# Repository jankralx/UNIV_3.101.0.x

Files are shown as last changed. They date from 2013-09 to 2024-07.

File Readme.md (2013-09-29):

UNIV 3.101.0.x
============

RS232C INTERFACE - PC interface and interface to other devices with serial port

Device webpage: http://hapcan.com/devices/universal/univ_3/univ_3-101-0-x/

Hardware created in Eagle PCB Software http://www.cadsoftusa.com/

Firmware created in Microchip MPLAB http://www.microchip.com/mplabide/ in assembly language

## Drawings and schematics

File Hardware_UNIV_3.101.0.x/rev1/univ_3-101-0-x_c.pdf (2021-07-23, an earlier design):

## RS232C INTERFACE

# UNIV 3.101.0.x

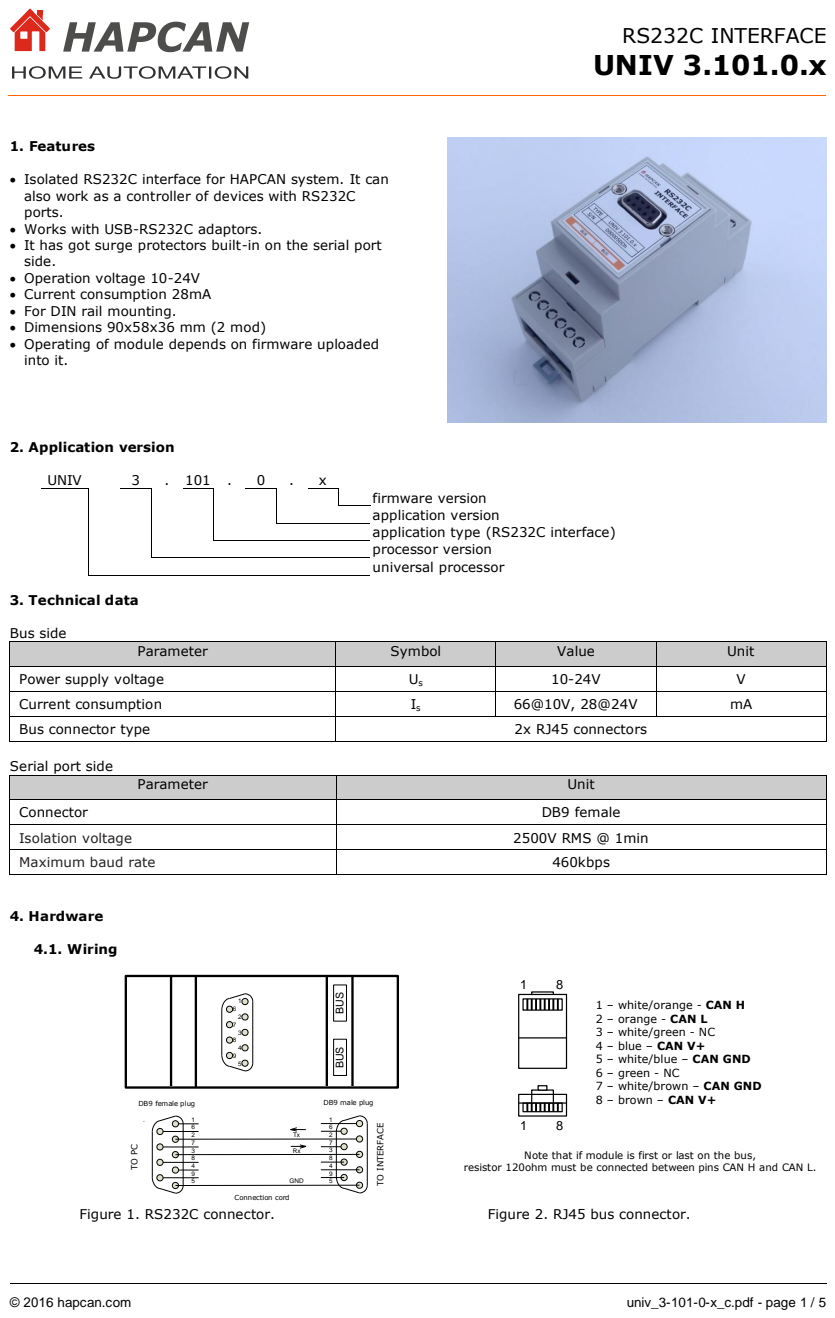
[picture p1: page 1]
© 2016 hapcan.com; univ_3-101-0-x_c.pdf - page 1 / 5; 1. Features; 2. Application version; UNIV; 3. Technical data; Bus side; 4. Hardware; 4.1. Wiring; Figure 1. RS232C connector.; Figure 2. RJ45 bus connector.; DO KOMPUTERA; BUS BUS; DB9 Wtyk żeński; DB9 Wtyk męski; GND; DO INTERFEJSU; PRZEWÓD POŁĄCZENIOWY; TO INTERFACE; Connection cord

• Isolated RS232C interface for HAPCAN system. It can
also work as a controller of devices with RS232C
ports.
• Works with USB-RS232C adaptors.
• It has got surge protectors built-in on the serial port
side.
• Operation voltage 10-24V
• Current consumption 28mA
• For DIN rail mounting.
• Dimensions 90x58x36 mm (2 mod)
• Operating of module depends on firmware uploaded
into it.

firmware version
application version
application type (RS232C interface)
processor version
universal processor

Parameter | Symbol | Value | Unit

Power supply voltage | Us | 10-24V | V

Current consumption | Is | 66@10V, 28@24V | mA

Bus connector type | 2x RJ45 connectors

Serial port side

Parameter | Unit

Connector | DB9 female

Isolation voltage | 2500V RMS @ 1min

Maximum baud rate | 460kbps

1 – white/orange - CAN H
2 – orange - CAN L
3 – white/green - NC
4 – blue – CAN V+
5 – white/blue – CAN GND
6 – green - NC
7 – white/brown – CAN GND
8 – brown – CAN V+

TO PC DB9 female plug DB9 male plug

Note that if module is first or last on the bus,

resistor 120ohm must be connected between pins CAN H and CAN L.

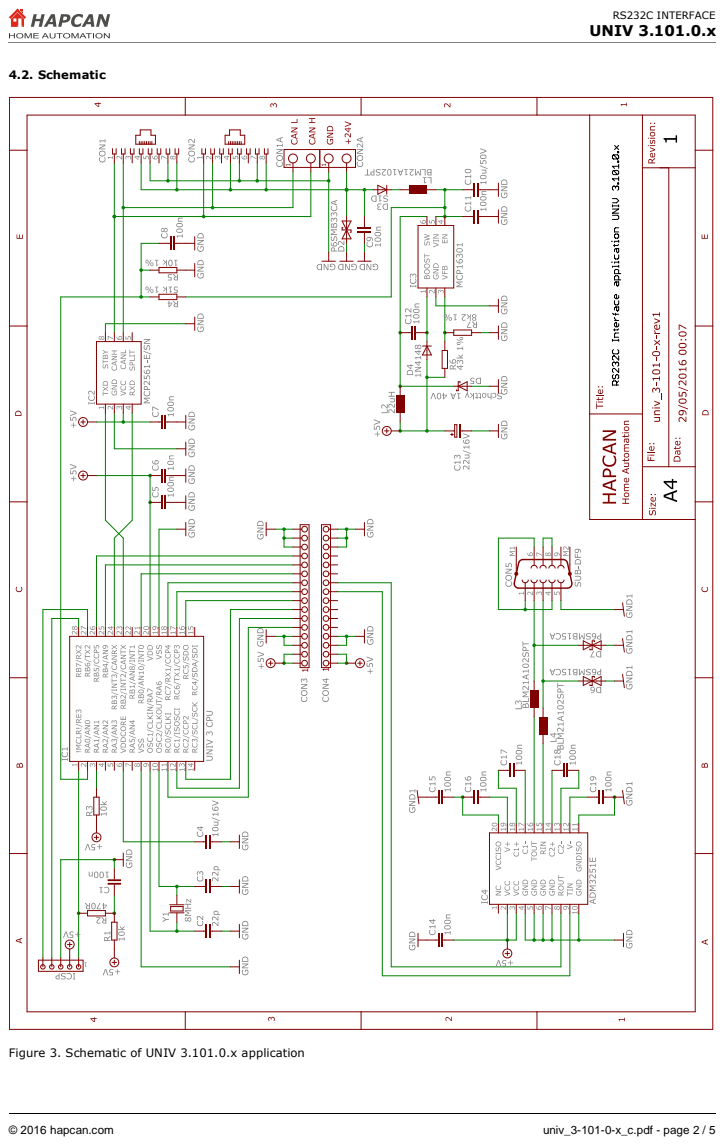
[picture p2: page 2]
4.2. Schematic

Figure 3. Schematic of UNIV 3.101.0.x application

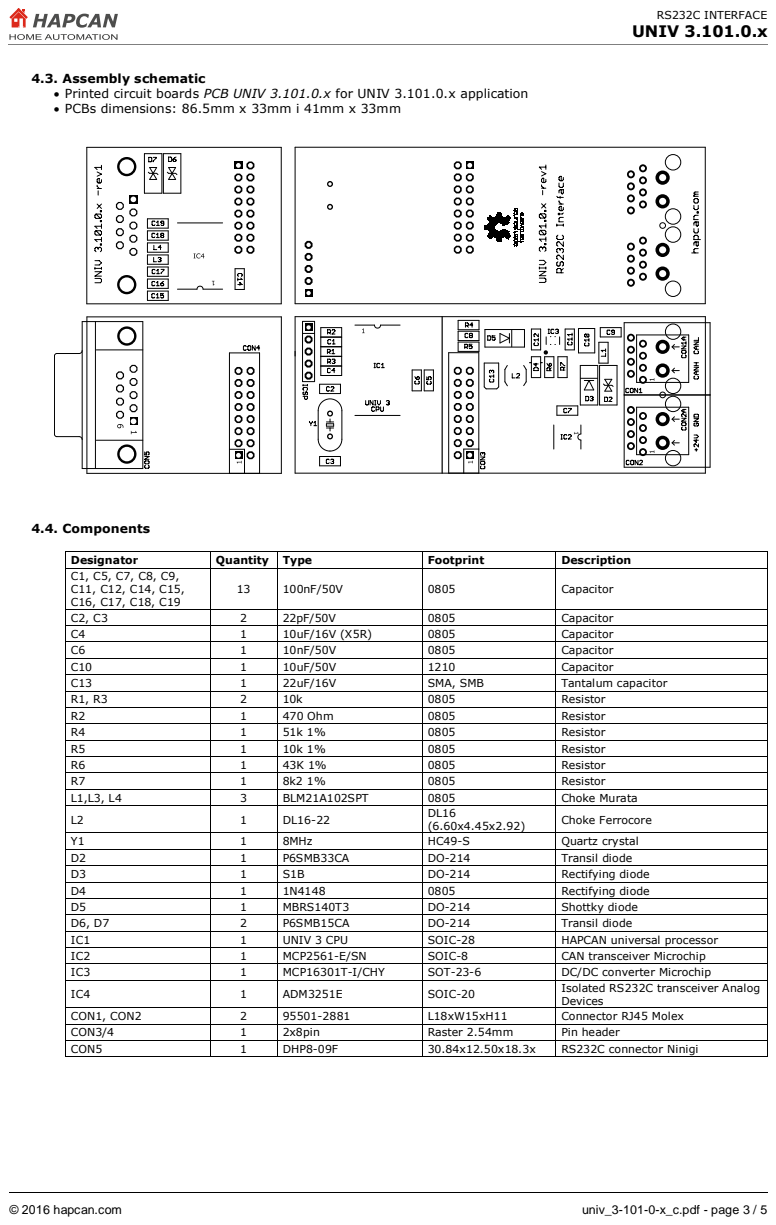
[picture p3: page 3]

4.3. Assembly schematic
• Printed circuit boards PCB UNIV 3.101.0.x for UNIV 3.101.0.x application
• PCBs dimensions: 86.5mm x 33mm i 41mm x 33mm

Designator | Quantity | Type | Footprint | Description
C1, C5, C7, C8, C9, C11, C12, C14, C15, C16, C17, C18, C19 | 13 | 100nF/50V | 0805 | Capacitor

C2, C3 | 2 | 22pF/50V | 0805 | Capacitor
C4 | 1 | 10uF/16V (X5R) | 0805 | Capacitor
C6 | 1 | 10nF/50V | 0805 | Capacitor
C10 | 1 | 10uF/50V | 1210 | Capacitor
C13 | 1 | 22uF/16V | SMA, SMB | Tantalum capacitor
R1, R3 | 2 | 10k | 0805 | Resistor
R2 | 1 | 470 Ohm | 0805 | Resistor
R4 | 1 | 51k 1% | 0805 | Resistor
R5 | 1 | 10k 1% | 0805 | Resistor
R6 | 1 | 43K 1% | 0805 | Resistor
R7 | 1 | 8k2 1% | 0805 | Resistor
L1,L3, L4 | 3 | BLM21A102SPT | 0805 | Choke Murata
L2 | 1 | DL16-22 | DL16 (6.60x4.45x2.92) | Choke Ferrocore

Y1 | 1 | 8MHz | HC49-S | Quartz crystal
D2 | 1 | P6SMB33CA | DO-214 | Transil diode
D3 | 1 | S1B | DO-214 | Rectifying diode
D4 | 1 | 1N4148 | 0805 | Rectifying diode
D5 | 1 | MBRS140T3 | DO-214 | Shottky diode
D6, D7 | 2 | P6SMB15CA | DO-214 | Transil diode
IC1 | 1 | UNIV 3 CPU | SOIC-28 | HAPCAN universal processor
IC2 | 1 | MCP2561-E/SN | SOIC-8 | CAN transceiver Microchip
IC3 | 1 | MCP16301T-I/CHY | SOT-23-6 | DC/DC converter Microchip
IC4 | 1 | ADM3251E | SOIC-20 | Isolated RS232C transceiver Analog Devices

CON1, CON2 | 2 | 95501-2881 | L18xW15xH11 | Connector RJ45 Molex
CON3/4 | 1 | 2x8pin | Raster 2.54mm | Pin header
CON5 | 1 | DHP8-09F | 30.84x12.50x18.3x | RS232C connector Ninigi

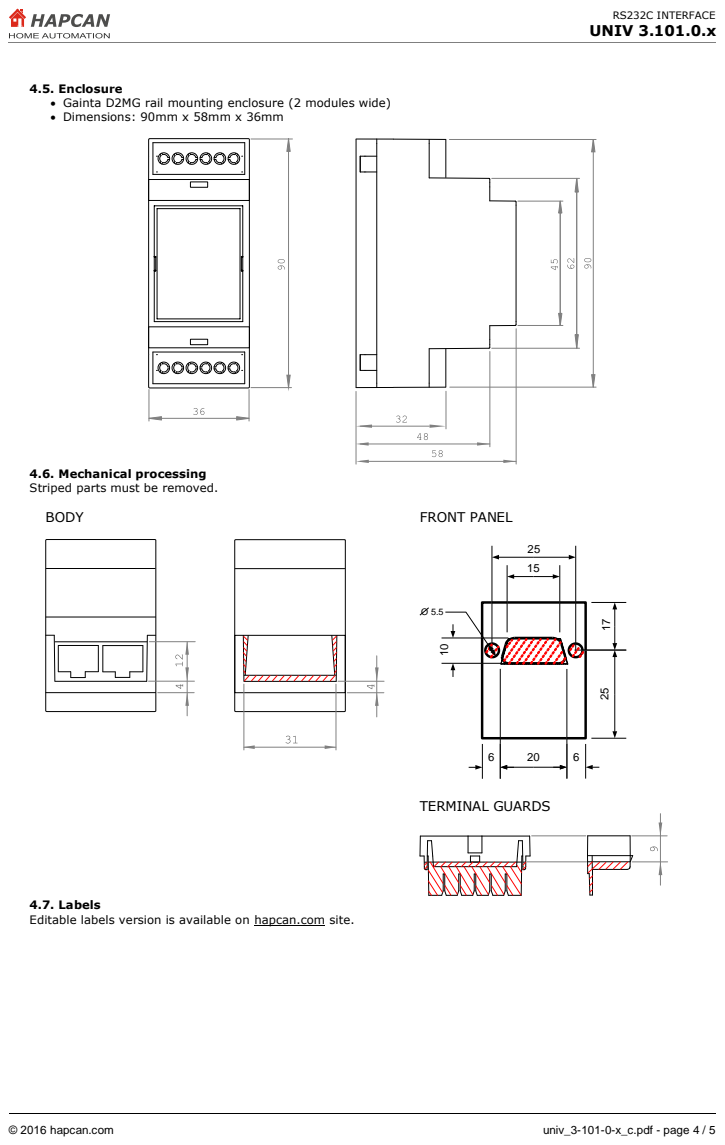
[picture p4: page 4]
BODY; FRONT PANEL; TERMINAL GUARDS

4.5. Enclosure
• Gainta D2MG rail mounting enclosure (2 modules wide)
• Dimensions: 90mm x 58mm x 36mm

4.6. Mechanical processing
Striped parts must be removed.

4.7. Labels
Editable labels version is available on hapcan.com site.

RS232C
Interface
TYPE | UNIV 3.101.0.x
S/N | 0000050Dh
BUS | BUS

### 5. Commissioning

### 5.1. CPU voltage measurement

After verifying the correctness and quality of the soldering, the bus voltage should be connected while measuring the processor voltage. To do this, connect a voltmeter to pins 2 and 3 of the ICSP connector. Processor supply voltage should be about 5V.

Figure 4. CPU voltage measurement

### 5.2. Checking the CPU clock

Proper operation of the CPU can be checked by temporarily connecting the LED to pins 3 and 5 of the ICSP connector. When device is powered, the LED should light up four times in the sequence 0.5 second on - 0.5 second off. If the processor is in programming mode, the LED lights up only once for 50ms.

Figure 5. Checking the CPU clock

### 5.3. Firmware uploading

The device requires a firmware uploading for proper operation. It can be done with HAPCAN Programmer software. Both, firmware and HAPCAN Programmer can be downloaded from hapcan.com website.
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

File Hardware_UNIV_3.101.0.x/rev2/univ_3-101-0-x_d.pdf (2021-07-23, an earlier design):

## RS232C INTERFACE

# UNIV 3.101.0.x

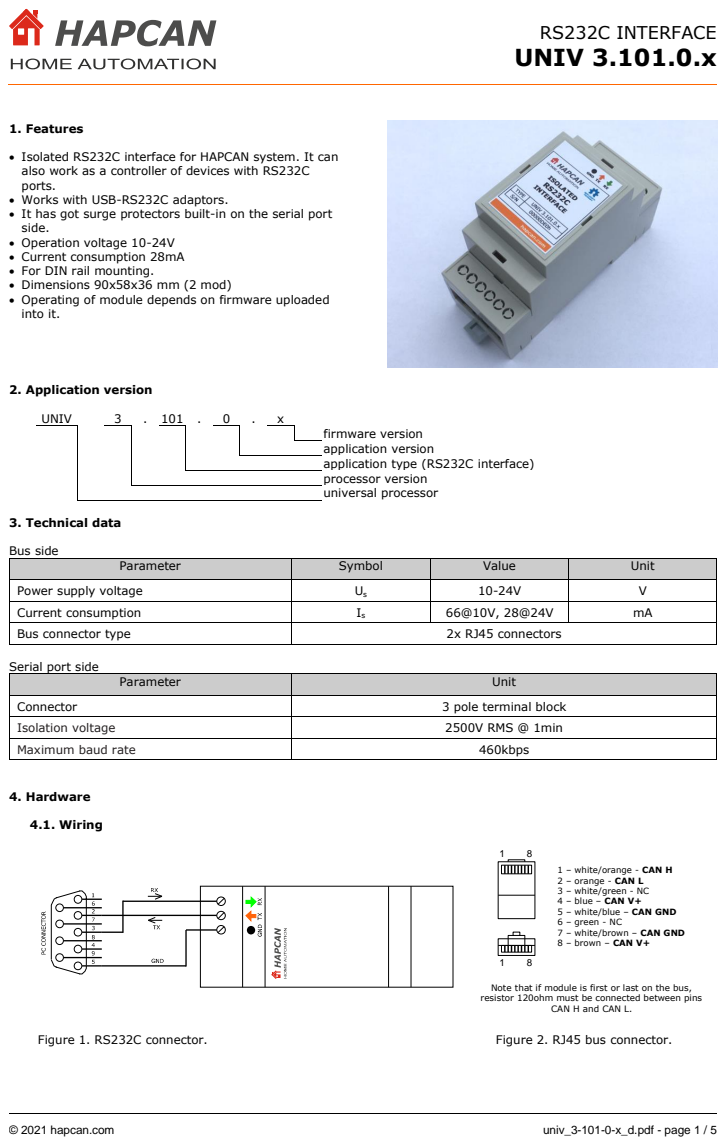
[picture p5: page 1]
© 2021 hapcan.com; univ_3-101-0-x_d.pdf - page 1 / 5; 1. Features; 2. Application version; UNIV; 3. Technical data; Bus side; 4. Hardware; 4.1. Wiring; Figure 1. RS232C connector.; Figure 2. RJ45 bus connector.

• Isolated RS232C interface for HAPCAN system. It can
also work as a controller of devices with RS232C
ports.
• Works with USB-RS232C adaptors.
• It has got surge protectors built-in on the serial port
side.
• Operation voltage 10-24V
• Current consumption 28mA
• For DIN rail mounting.
• Dimensions 90x58x36 mm (2 mod)
• Operating of module depends on firmware uploaded
into it.

firmware version
application version
application type (RS232C interface)
processor version
universal processor

Parameter | Symbol | Value | Unit

Power supply voltage | Us | 10-24V | V
Current consumption | Is | 66@10V, 28@24V | mA
Bus connector type | 2x RJ45 connectors

Serial port side

Parameter | Unit

Connector | 3 pole terminal block
Isolation voltage | 2500V RMS @ 1min
Maximum baud rate | 460kbps

1 – white/orange - CAN H
2 – orange - CAN L
3 – white/green - NC
4 – blue – CAN V+
5 – white/blue – CAN GND
6 – green - NC
7 – white/brown – CAN GND
8 – brown – CAN V+

Note that if module is first or last on the bus,
resistor 120ohm must be connected between pins

CAN H and CAN L.

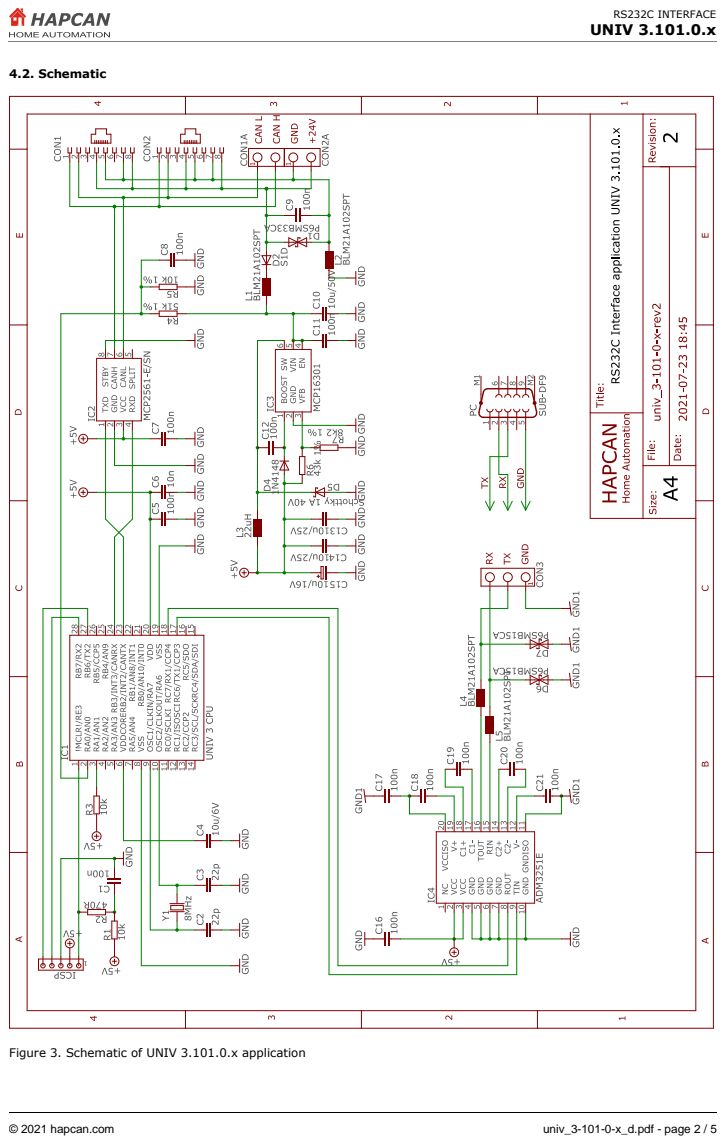
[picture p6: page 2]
4.2. Schematic

Figure 3. Schematic of UNIV 3.101.0.x application

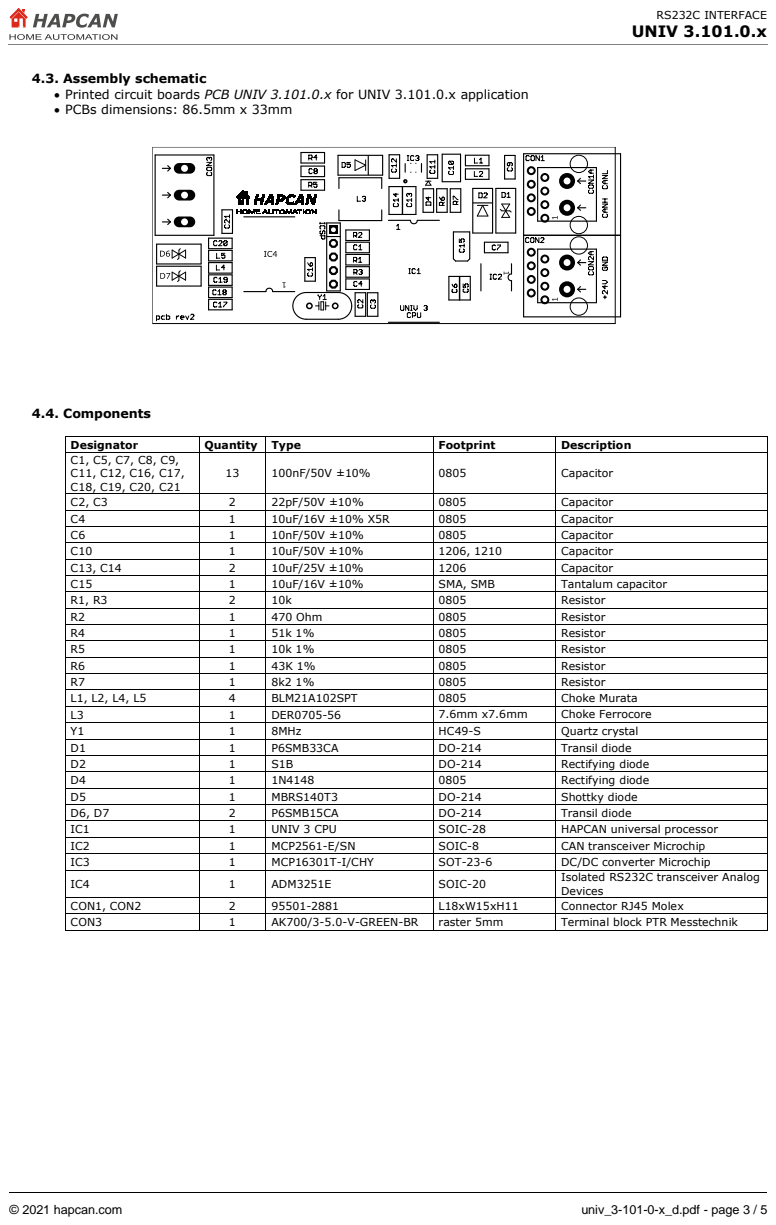
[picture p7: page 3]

4.3. Assembly schematic
• Printed circuit boards PCB UNIV 3.101.0.x for UNIV 3.101.0.x application
• PCBs dimensions: 86.5mm x 33mm

Designator | Quantity | Type | Footprint | Description
C1, C5, C7, C8, C9, C11, C12, C16, C17, C18, C19, C20, C21 | 13 | 100nF/50V ±10% | 0805 | Capacitor

C2, C3 | 2 | 22pF/50V ±10% | 0805 | Capacitor
C4 | 1 | 10uF/16V ±10% X5R | 0805 | Capacitor
C6 | 1 | 10nF/50V ±10% | 0805 | Capacitor
C10 | 1 | 10uF/50V ±10% | 1206, 1210 | Capacitor
C13, C14 | 2 | 10uF/25V ±10% | 1206 | Capacitor
C15 | 1 | 10uF/16V ±10% | SMA, SMB | Tantalum capacitor
R1, R3 | 2 | 10k | 0805 | Resistor
R2 | 1 | 470 Ohm | 0805 | Resistor
R4 | 1 | 51k 1% | 0805 | Resistor
R5 | 1 | 10k 1% | 0805 | Resistor
R6 | 1 | 43K 1% | 0805 | Resistor
R7 | 1 | 8k2 1% | 0805 | Resistor
L1, L2, L4, L5 | 4 | BLM21A102SPT | 0805 | Choke Murata
L3 | 1 | DER0705-56 | 7.6mm x7.6mm | Choke Ferrocore
Y1 | 1 | 8MHz | HC49-S | Quartz crystal
D1 | 1 | P6SMB33CA | DO-214 | Transil diode
D2 | 1 | S1B | DO-214 | Rectifying diode
D4 | 1 | 1N4148 | 0805 | Rectifying diode
D5 | 1 | MBRS140T3 | DO-214 | Shottky diode
D6, D7 | 2 | P6SMB15CA | DO-214 | Transil diode
IC1 | 1 | UNIV 3 CPU | SOIC-28 | HAPCAN universal processor
IC2 | 1 | MCP2561-E/SN | SOIC-8 | CAN transceiver Microchip
IC3 | 1 | MCP16301T-I/CHY | SOT-23-6 | DC/DC converter Microchip
IC4 | 1 | ADM3251E | SOIC-20 | Isolated RS232C transceiver Analog Devices

CON1, CON2 | 2 | 95501-2881 | L18xW15xH11 | Connector RJ45 Molex
CON3 | 1 | AK700/3-5.0-V-GREEN-BR | raster 5mm | Terminal block PTR Messtechnik

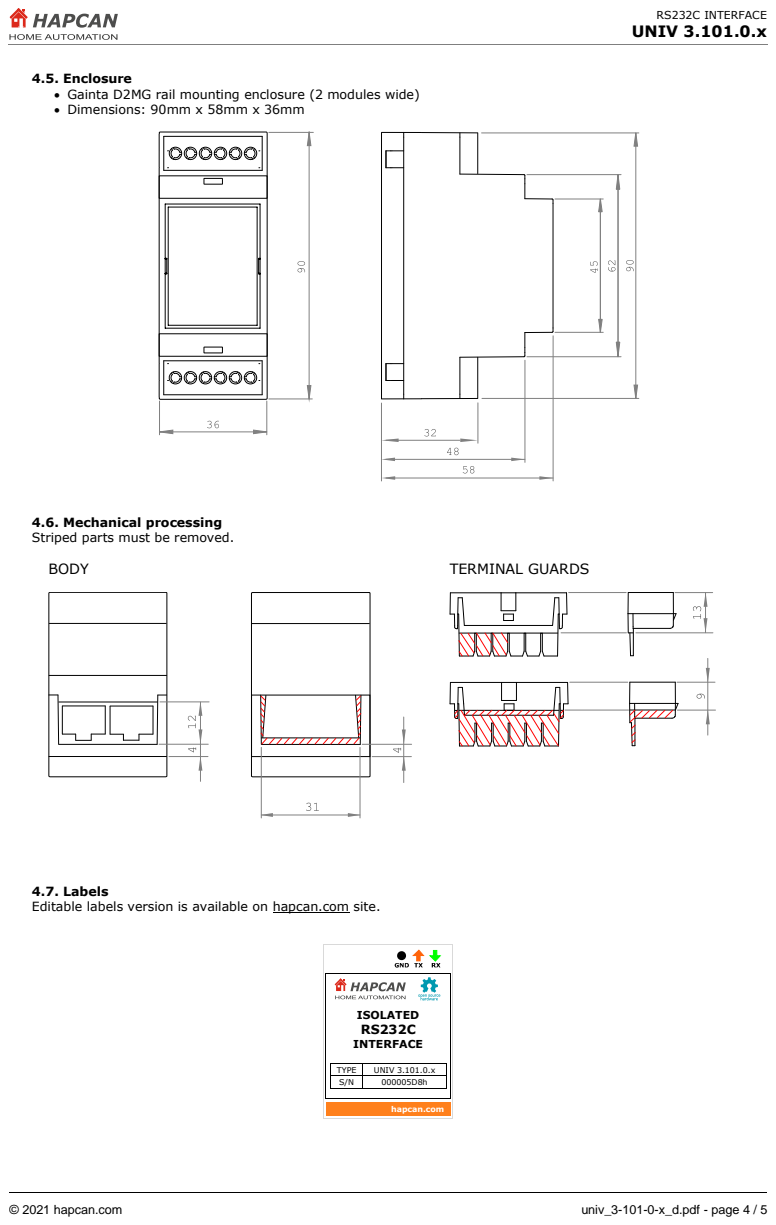
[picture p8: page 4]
BODY; TERMINAL GUARDS; ISOLATED RS232C INTERFACE; hapcan.com

4.5. Enclosure
• Gainta D2MG rail mounting enclosure (2 modules wide)
• Dimensions: 90mm x 58mm x 36mm

4.6. Mechanical processing
Striped parts must be removed.

4.7. Labels
Editable labels version is available on hapcan.com site.

TYPE | UNIV 3.101.0.x
S/N | 000005D8h

### 5. Commissioning

### 5.1. CPU voltage measurement

After verifying the correctness and quality of the soldering, the bus voltage should be connected while measuring the processor voltage. To do this, connect a voltmeter to pins 2 and 3 of the ICSP connector. Processor supply voltage should be about 5V.

Figure 4. CPU voltage measurement

### 5.2. Checking the CPU clock

Proper operation of the CPU can be checked by temporarily connecting the LED to pins 3 and 5 of the ICSP connector. When device is powered, the LED should light up four times in the sequence 0.5 second on - 0.5 second off. The LED lights up only once for 50ms if processor is in the programming mode.

Figure 5. Checking the CPU clock

### 5.3. Firmware uploading

The device requires a firmware uploading for proper operation. It can be done with HAPCAN Programmer software. Both, firmware and HAPCAN Programmer can be downloaded from hapcan.com website.
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

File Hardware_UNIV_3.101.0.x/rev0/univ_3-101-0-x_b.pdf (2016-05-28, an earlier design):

## RS232C INTERFACE

# UNIV 3.101.0.x

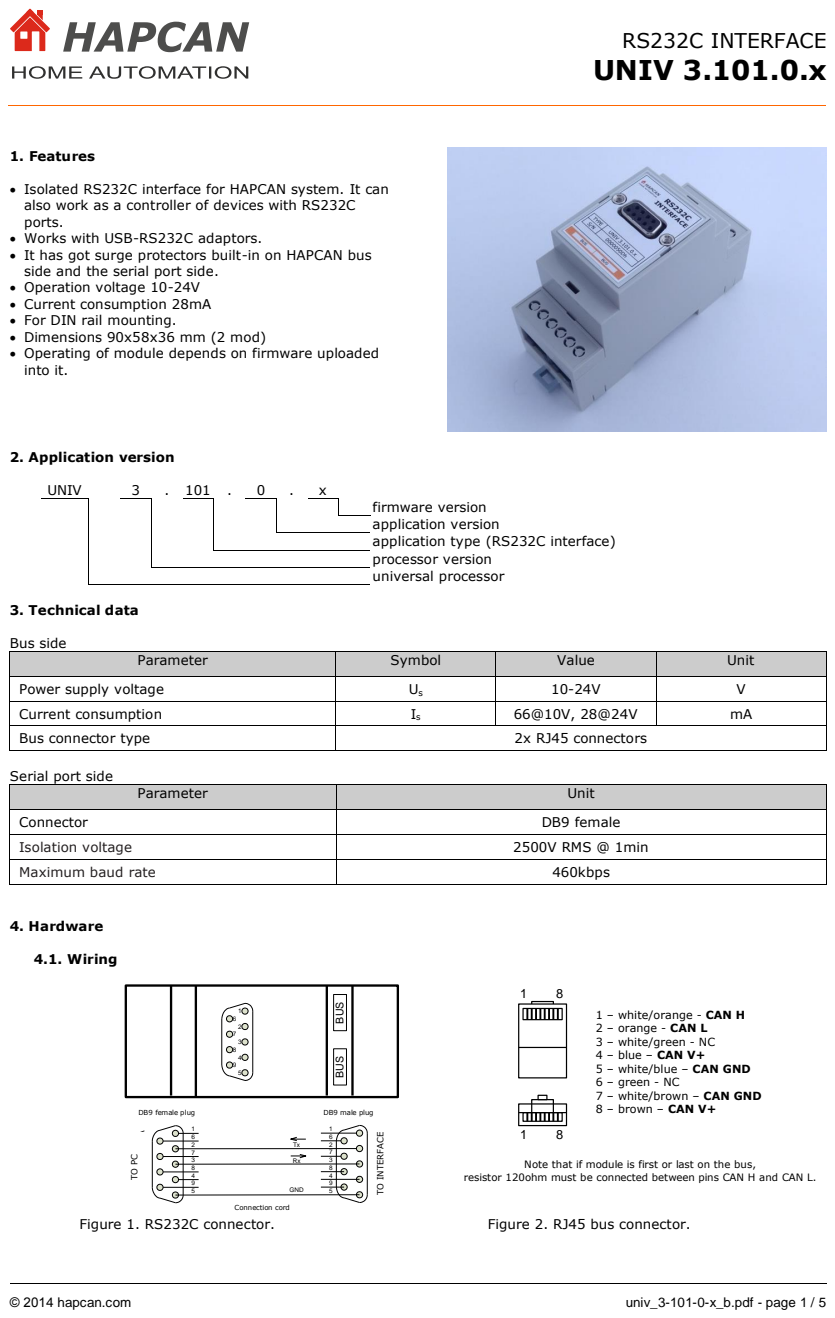
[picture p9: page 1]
© 2014 hapcan.com; univ_3-101-0-x_b.pdf - page 1 / 5; 1. Features; 2. Application version; UNIV; 3. Technical data; Bus side; 4. Hardware; 4.1. Wiring; Figure 1. RS232C connector.; Figure 2. RJ45 bus connector.; DO KOMPUTERA; BUS BUS; DB9 Wtyk żeński; DB9 Wtyk męski; GND; DO INTERFEJSU; PRZEWÓD POŁĄCZENIOWY; TO INTERFACE; Connection cord

• Isolated RS232C interface for HAPCAN system. It can
also work as a controller of devices with RS232C
ports.
• Works with USB-RS232C adaptors.
• It has got surge protectors built-in on HAPCAN bus
side and the serial port side.
• Operation voltage 10-24V
• Current consumption 28mA
• For DIN rail mounting.
• Dimensions 90x58x36 mm (2 mod)
• Operating of module depends on firmware uploaded
into it.

firmware version
application version
application type (RS232C interface)
processor version
universal processor

Parameter | Symbol | Value | Unit

Power supply voltage | Us | 10-24V | V

Current consumption | Is | 66@10V, 28@24V | mA

Bus connector type | 2x RJ45 connectors

Serial port side

Parameter | Unit

Connector | DB9 female

Isolation voltage | 2500V RMS @ 1min

Maximum baud rate | 460kbps

1 – white/orange - CAN H
2 – orange - CAN L
3 – white/green - NC
4 – blue – CAN V+
5 – white/blue – CAN GND
6 – green - NC
7 – white/brown – CAN GND
8 – brown – CAN V+

TO PC DB9 female plug DB9 male plug

Note that if module is first or last on the bus,

resistor 120ohm must be connected between pins CAN H and CAN L.

## UNIV 3.101.0.x

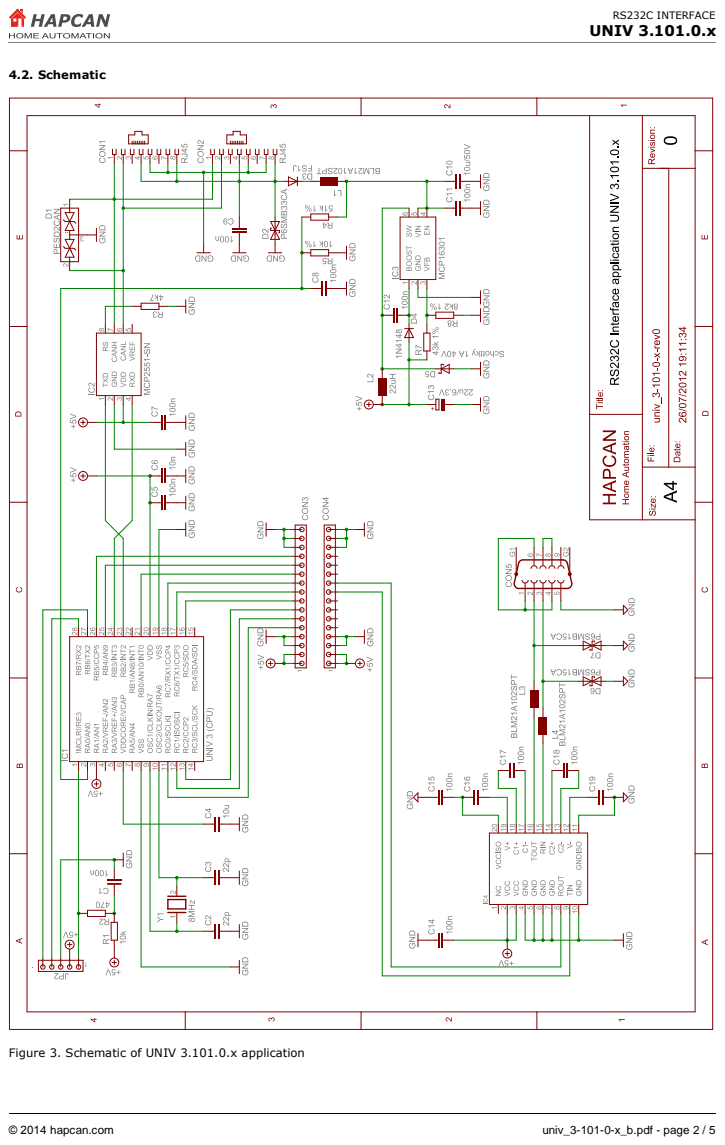
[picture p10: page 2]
4.2. Schematic

Figure 3. Schematic of UNIV 3.101.0.x application

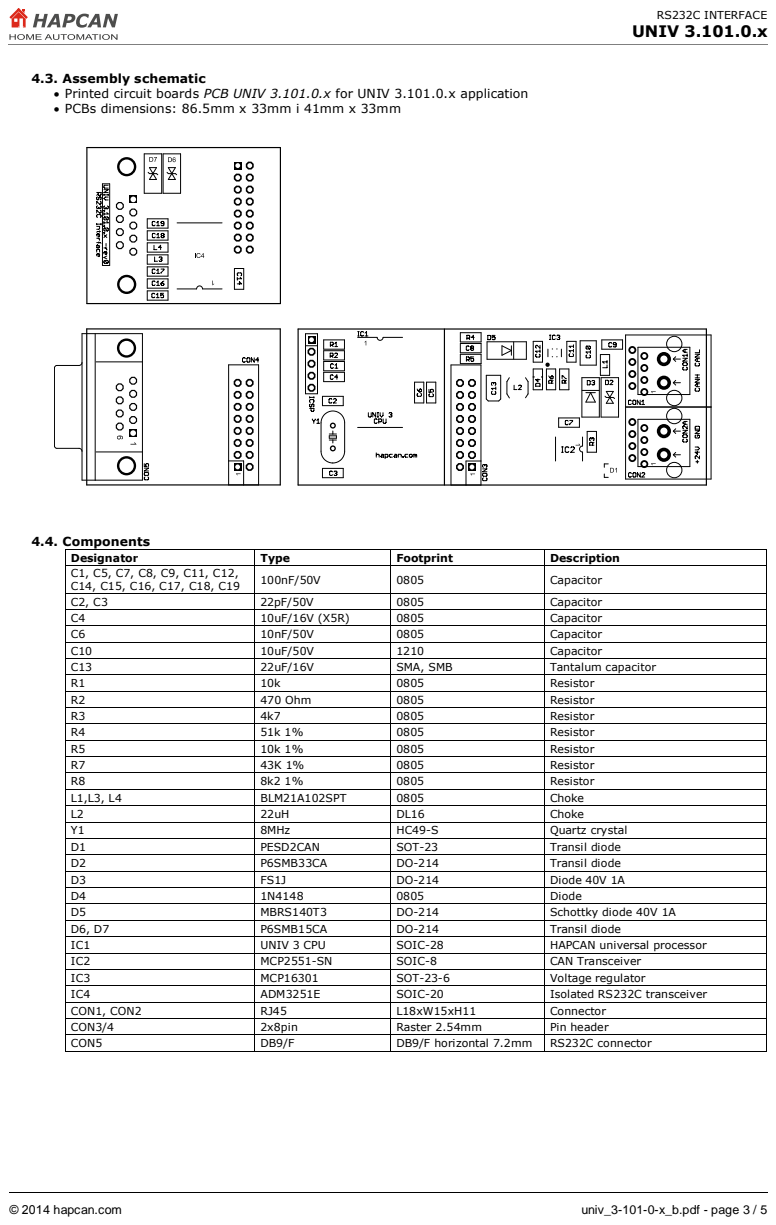
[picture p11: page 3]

4.3. Assembly schematic
• Printed circuit boards PCB UNIV 3.101.0.x for UNIV 3.101.0.x application
• PCBs dimensions: 86.5mm x 33mm i 41mm x 33mm

Designator | Type | Footprint | Description
C1, C5, C7, C8, C9, C11, C12, C14, C15, C16, C17, C18, C19 | 100nF/50V | 0805 | Capacitor

C2, C3 | 22pF/50V | 0805 | Capacitor
C4 | 10uF/16V (X5R) | 0805 | Capacitor
C6 | 10nF/50V | 0805 | Capacitor
C10 | 10uF/50V | 1210 | Capacitor
C13 | 22uF/16V | SMA, SMB | Tantalum capacitor
R1 | 10k | 0805 | Resistor
R2 | 470 Ohm | 0805 | Resistor
R3 | 4k7 | 0805 | Resistor
R4 | 51k 1% | 0805 | Resistor
R5 | 10k 1% | 0805 | Resistor
R7 | 43K 1% | 0805 | Resistor
R8 | 8k2 1% | 0805 | Resistor
L1,L3, L4 | BLM21A102SPT | 0805 | Choke
L2 | 22uH | DL16 | Choke
Y1 | 8MHz | HC49-S | Quartz crystal
D1 | PESD2CAN | SOT-23 | Transil diode
D2 | P6SMB33CA | DO-214 | Transil diode
D3 | FS1J | DO-214 | Diode 40V 1A
D4 | 1N4148 | 0805 | Diode
D5 | MBRS140T3 | DO-214 | Schottky diode 40V 1A
D6, D7 | P6SMB15CA | DO-214 | Transil diode
IC1 | UNIV 3 CPU | SOIC-28 | HAPCAN universal processor
IC2 | MCP2551-SN | SOIC-8 | CAN Transceiver
IC3 | MCP16301 | SOT-23-6 | Voltage regulator
IC4 | ADM3251E | SOIC-20 | Isolated RS232C transceiver
CON1, CON2 | RJ45 | L18xW15xH11 | Connector
CON3/4 | 2x8pin | Raster 2.54mm | Pin header
CON5 | DB9/F | DB9/F horizontal 7.2mm | RS232C connector

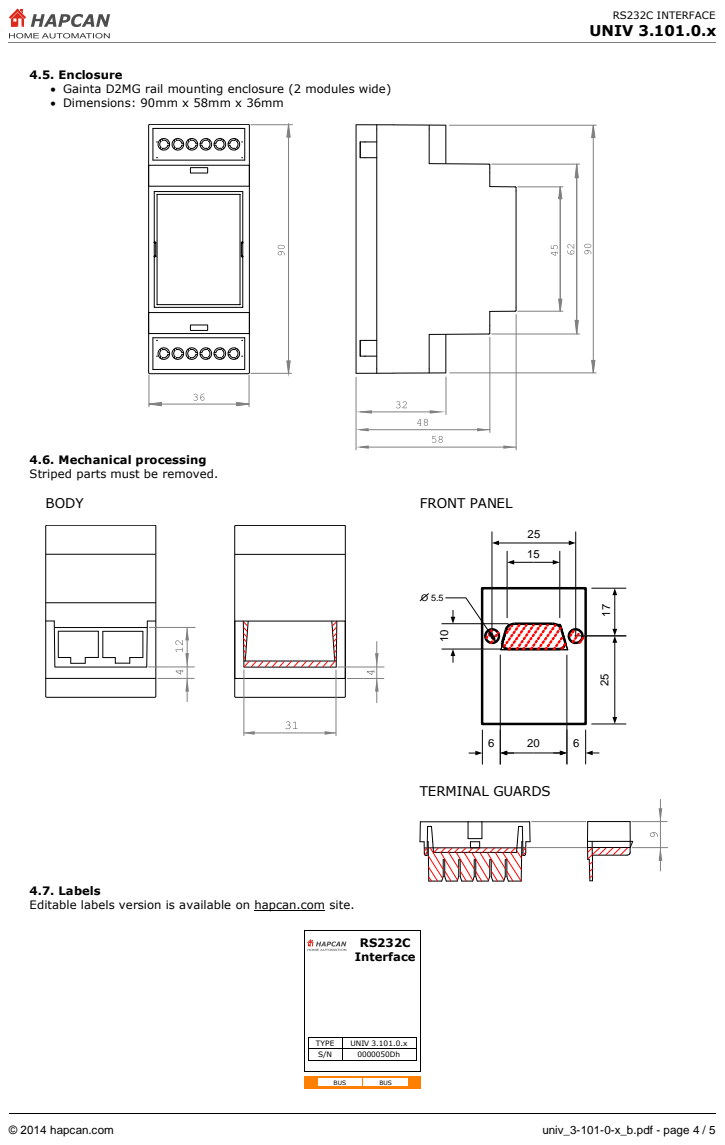
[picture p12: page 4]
BODY; FRONT PANEL; TERMINAL GUARDS; RS232C Interface; BUS

4.5. Enclosure
• Gainta D2MG rail mounting enclosure (2 modules wide)
• Dimensions: 90mm x 58mm x 36mm

4.6. Mechanical processing
Striped parts must be removed.

4.7. Labels
Editable labels version is available on hapcan.com site.

TYPE | UNIV 3.101.0.x
S/N | 0000050Dh

### 5. Commissioning

### 5.1. CPU voltage measurement

After verifying the correctness and quality of the soldering, the bus voltage should be connected while measuring the processor voltage. To do this, connect a voltmeter to pins 2 and 3 of the ICSP connector. Processor supply voltage should be about 5V.

Figure 4. CPU voltage measurement

### 5.2. Checking the CPU clock

Proper operation of the CPU can be checked by temporarily connecting the LED to pins 3 and 5 of the ICSP connector. When device is powered, the LED should light up four times in the sequence 0.5 second on - 0.5 second off. If the processor is in programming mode, the LED lights up only once for 50ms.

Figure 5. Checking the CPU clock

### 5.3. Firmware uploading

The device requires a firmware uploading for proper operation. It can be done with HAPCAN Programmer software. Both, firmware and HAPCAN Programmer can be downloaded from hapcan.com website.

### 6. Document version

File | Description | Date
univ_3-101-0-x_a.pdf | Original version | July 2012
univ_3-101-0-x_b.pdf | Enclosure has been changed | June 2014

1
V

### ICSP

1
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

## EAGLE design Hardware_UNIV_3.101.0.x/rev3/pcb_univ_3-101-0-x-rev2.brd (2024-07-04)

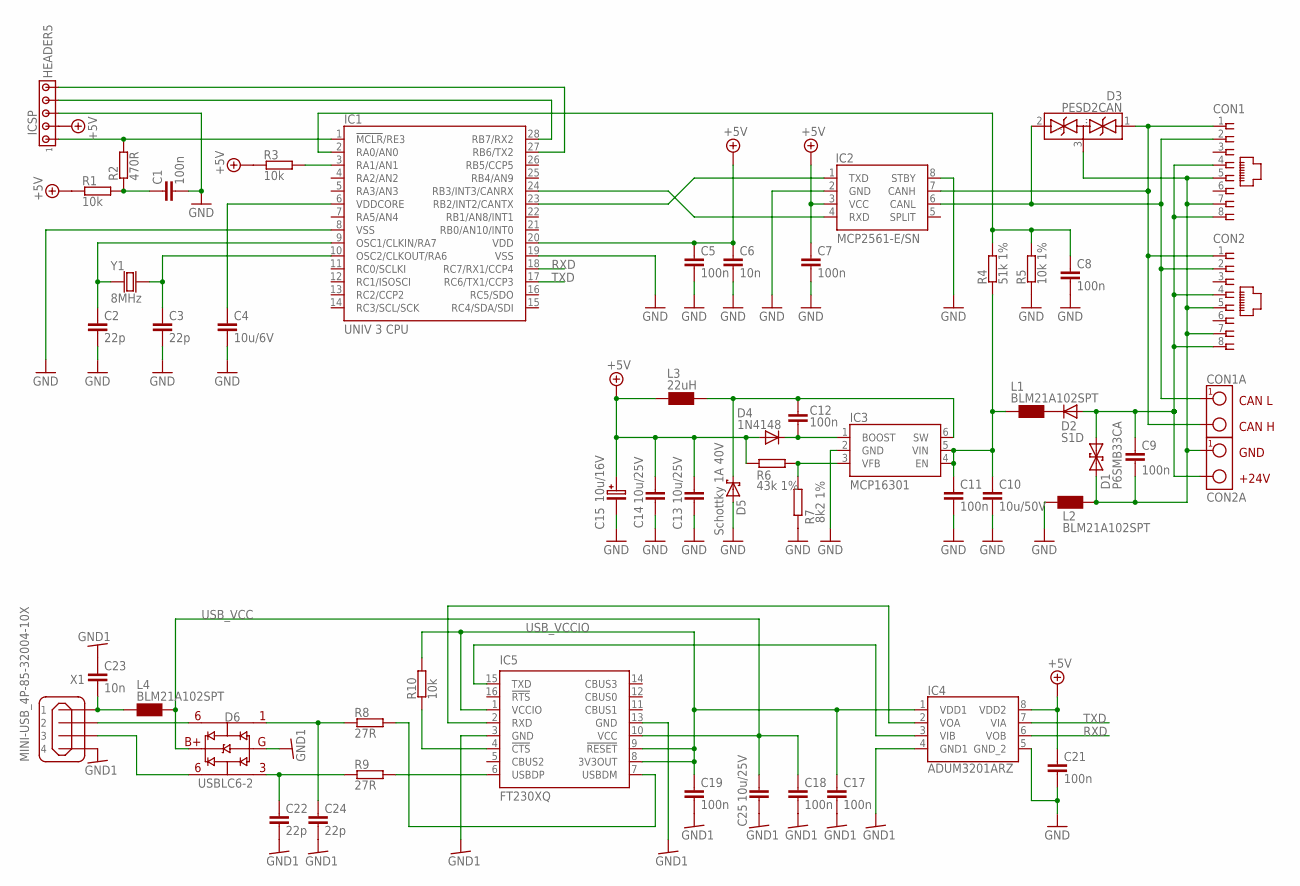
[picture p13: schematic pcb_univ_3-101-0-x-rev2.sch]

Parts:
C1, C5, C7, C8, C9, C11, C12, C17, C18, C19, C21: 100n; 0805
C2, C3, C22, C24: 22p; 0805
C4: 10u/6V; 0805
C6, C23: 10n; 0805
C10: 10u/50V; 1210
C13, C14, C25: 10u/25V; 1206
C15: 10u/16V; SMC_B
CON1, CON2: RJ45-SOCKET; RJ45-PCB-SOCKET
CON1A, CON2A: TERMINAL-2; ARK2-5X10,5MM
D1: P6SMB33CA; DO-214_TRANSIL2
D2: S1D; DO-214
D3: PESD2CAN; SOT-23
D4: 1N4148; 0805
D5: Schottky 1A 40V; DO-214
D6: USBLC6-2; SOT23-6L; MFR_PART_NO USBLC6-2SC6
IC1: UNIV 3 CPU; UNIV3CPU
IC2: MCP2561-E/SN; SO-08
IC3: MCP16301; SOT-23-6
IC4: ADUM3201ARZ; SOIC127P600X175-8N
IC5: FT230XQ; QFN16
ICSP: HEADER5; SIP-5
L1, L2, L4: BLM21A102SPT; 0805
L3: 22uH; CHOKE-DER0705
R1, R3, R10: 10k; 0805
R2: 470R; 0805
R4: 51k 1%; 0805
R5: 10k 1%; 0805
R6: 43k 1%; 0805
R7: 8k2 1%; 0805
R8, R9: 27R; 0805
X1: MINI-USB_4P-85-32004-10X; 85-32004-10X
Y1: 8MHz; CRYSTAL-HC49V

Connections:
+5V: C5.1, C6.1, C7.1, C13.1, C14.1, C15.+ (1), C21.1, D4.2 (A), IC1.20 (VDD), IC2.3 (VCC), IC4.8 (VDD2), ICSP.2, L3.1, R1.1, R3.1, R6.1
GND: C1.2, C2.2, C3.2, C4.2, C5.2, C6.2, C7.2, C8.2, C10.2, C11.2, C13.2, C14.2, C15.- (2), C21.2, D5.A, IC1.8 (VSS), IC1.19 (VSS), IC2.2 (GND), IC2.8 (STBY), IC3.2 (GND), IC4.5 (GND_2), ICSP.3, L2.1, R5.1, R7.1
GNDIO: C17.2, C18.2, C19.2, C22.2, C23.1, C24.2, C25.2, D6.2 (G), IC4.4 (GND1), IC5.3 (GND), IC5.13 (GND), X1.4
ICSP: IC1.1 (!MCLR!/RE3), ICSP.1, R2.2
unnamed: D6.6, X1.2
unnamed: IC1.24 (RB3/INT3/CANRX), IC2.4 (RXD)
unnamed: IC1.23 (RB2/INT2/CANTX), IC2.1 (TXD)
unnamed: D6.4, X1.3
unnamed: C12.1, D5.C, IC3.6 (SW), L3.2
unnamed: IC3.3 (VFB), R6.2, R7.2
unnamed: C1.1, R1.2, R2.1
unnamed: C8.1, IC1.2 (RA0/AN0), R4.2, R5.2
unnamed: CON1.1, CON1A.2, CON2.1, D3.1 (.), IC2.7 (CANH)
unnamed: IC1.28 (RB7/RX2), ICSP.4
unnamed: C2.1, IC1.9 (OSC1/CLKIN/RA7), Y1.1
unnamed: IC1.3 (RA1/AN1), R3.2
unnamed: CON1.2, CON1A.1, CON2.2, D3.2 (..), IC2.6 (CANL)
unnamed: IC1.27 (RB6/TX2), ICSP.5
unnamed: C3.1, IC1.10 (OSC2/CLKOUT/RA6), Y1.2
unnamed: C10.1, C11.1, IC3.4 (EN), IC3.5 (VIN), L1.1, R4.1
unnamed: C23.2, L4.2, X1.1
unnamed: C9.2, CON1.5, CON1.7, CON2.5, CON2.7, CON2A.1, D1.C (2), D3.3 (...), L2.2
unnamed: IC4.2 (VOA), IC5.2 (RXD)
unnamed: C24.1, D6.1, R8.1
unnamed: C22.1, D6.3, R9.1
unnamed: IC5.6 (USBDP), R9.2
unnamed: IC5.7 (USBDM), R8.2
unnamed: IC4.3 (VIB), IC5.15 (TXD)
unnamed: IC5.4 (!CTS), R10.1
unnamed: C12.2, D4.1 (C), IC3.1 (BOOST)
unnamed: C4.1, IC1.6 (VDDCORE)
unnamed: C9.1, CON1.4, CON1.8, CON2.4, CON2.8, CON2A.2, D1.A (1), D2.A
unnamed: D2.C, L1.2
RXD: IC1.18 (RC7/RX1/CCP4), IC4.6 (VOB)
TXD: IC1.17 (RC6/TX1/CCP3), IC4.7 (VIA)
USB_VCC: C18.1, C25.1, D6.5 (B+), IC5.10 (VCC), L4.1
USB_VCCIO: C17.1, C19.1, IC4.1 (VDD1), IC5.1 (VCCIO), IC5.8 (3V3OUT), IC5.9 (!RESET), R10.2

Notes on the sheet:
CAN L
CAN H
GND
+24V

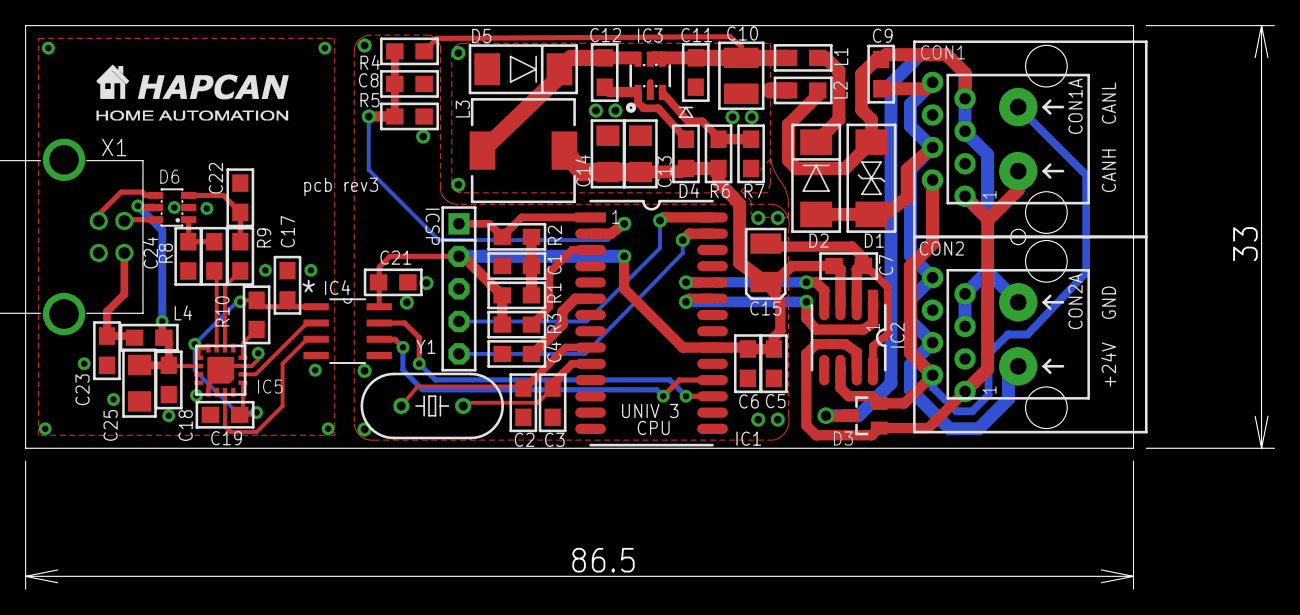
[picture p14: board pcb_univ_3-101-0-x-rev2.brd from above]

Board: 2 copper layers, 86.5 x 33.0 mm, 55 parts (0 on the bottom side), 37 nets.

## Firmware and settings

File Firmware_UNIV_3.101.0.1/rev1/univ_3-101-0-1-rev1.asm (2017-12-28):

;==============================================================================
;   HAPCAN - Home Automation Project Firmware (http://hapcan.com)
;   Copyright (C) 2017 hapcan.com
;
;   This program is free software: you can redistribute it and/or modify
;   it under the terms of the GNU General Public License as published by
;   the Free Software Foundation, either version 3 of the License, or
;   (at your option) any later version.
;
;   This program is distributed in the hope that it will be useful,
;   but WITHOUT ANY WARRANTY; without even the implied warranty of
;   MERCHANTABILITY or FITNESS FOR A PARTICULAR PURPOSE.  See the
;   GNU General Public License for more details.
;
;   You should have received a copy of the GNU General Public License
;   along with this program.  If not, see <http://www.gnu.org/licenses/>.
;==============================================================================
;   Filename:              univ_3-101-0-1.asm
;   Associated diagram:    univ_3-101-0-x.sch
;   Author:                Jacek Siwilo                          
;   Note:                  This module takes message from UART, matches it
;   agains UART/CAN boxes and sends defined in box the can message.
;   The message from CAN is matched against CAN/UART boxes and the module sends
;   to UART defined in box the uart message.
;   UART parameters can be choosen, default: 115200 bps, 8bits, start and stop
;   bits, 32MHz clock.
;==============================================================================
;   Revision History
;   Rev:  Date:     Details:
;   0     03.2015   Original version
;   1     12.2017   Updated with "univ3-routines-rev7.inc"
;==============================================================================
;===  FIRMWARE DEFINITIONS  ===================================================
;==============================================================================
    #define    ATYPE    .101                          ;application type [0-255]
    #define    AVERS    .0                         ;application version [0-255]
    #define    FVERS    .1                            ;firmware version [0-255]

    #define    FREV     .1                         ;firmware revision [0-65536]
;==============================================================================
;===  NEEDED FILES  ===========================================================
;==============================================================================
    LIST P=18F26K80                              ;directive to define processor
    #include <P18F26K80.INC>           ;processor specific variable definitions
    #include <univ_3-101-0-1-rev1.inc>                       ;project variables
INCLUDEDFILES   code
    #include <univ3-routines-rev7.inc>                     ;UNIV 3 CPU routines
;==============================================================================
;===  FIRMWARE CHECKSUM  ======================================================
;==============================================================================
FIRMCHKSM   code    0x001000
    DB      0x67, 0x13, 0xE6
;==============================================================================
;===  FIRMWARE ID  ============================================================
;==============================================================================
FIRMID      code    0x001010
    DB      0x30, 0x00, 0x03,ATYPE,AVERS,FVERS,FREV>>8,FREV
;            |     |     |     |     |     |     |_____|_____ firmware revision
;            |     |     |     |     |     |__________________ firmware version
;            |     |     |     |     |_____________________ application version
;            |     |     |     |______________________________ application type
;            |     |     |________________________________ hardware version '3'
;            |_____|______________________________________ hardware type 'UNIV'
;==============================================================================
;===  MOVED VECTORS  ==========================================================
;==============================================================================
;PROGRAM RESET VECTOR
FIRMRESET   code    0x1020
        goto    Main
;PROGRAM HIGH PRIORITY INTERRUPT VECTOR
FIRMHIGHINT code    0x1030
        call    HighInterrupt
        retfie
;RECEIVED MESSAGE VECTOR
FIRMLOWINT  code    0x1040
        call    LowInterrupt
        retfie

;==============================================================================
;===  FIRMWARE STARTS  ========================================================
;==============================================================================
FIRMSTART   code    0x001050
;------------------------------------------------------------------------------
;---  LOW PRIORITY INTERRUPT  -------------------------------------------------
;------------------------------------------------------------------------------
LowInterrupt
        movff	STATUS,STATUS_LOW           ;save STATUS register
        movff	WREG,WREG_LOW               ;save working register
        movff	BSR,BSR_LOW                 ;save BSR register
        movff	FSR0L,FSR0L_LOW             ;save other registers used in high int
        movff	FSR0H,FSR0H_LOW
        movff	FSR1L,FSR1L_LOW
        movff	FSR1H,FSR1H_LOW

    ;main firmware ready flag
        banksel FIRMREADY
        btfss   FIRMREADY,0
        bra     ExitLowInterrupt            ;main firmware is not ready yet
    ;CAN buffer
        banksel CANFULL
        btfsc   CANFULL,0  
        call    RS232WriteToCanRxFIFO		;receive and save message in RAM

ExitLowInterrupt
        movff	BSR_LOW,BSR                 ;restore BSR register
        movff	WREG_LOW,WREG               ;restore working register
        movff	STATUS_LOW,STATUS           ;restore STATUS register
        movff	FSR0L_LOW,FSR0L             ;restore other registers used in high int
        movff	FSR0H_LOW,FSR0H
        movff	FSR1L_LOW,FSR1L
        movff	FSR1H_LOW,FSR1H
    return

;------------------------------------------------------------------------------
;---  HIGH PRIORITY INTERRUPT  ------------------------------------------------
;------------------------------------------------------------------------------
HighInterrupt
        movff	STATUS,STATUS_HIGH          ;save STATUS register
        movff	WREG,WREG_HIGH              ;save working register
        movff	BSR,BSR_HIGH                ;save BSR register
        movff	FSR0L,FSR0L_HIGH            ;save other registers used in high int
        movff	FSR0H,FSR0H_HIGH
        movff	FSR1L,FSR1L_HIGH
        movff	FSR1H,FSR1H_HIGH

    ;main firmware ready flag
        banksel FIRMREADY
        btfss   FIRMREADY,0
        bra     ExitHighInterrupt           ;main firmware is not ready yet
    ;uart
        banksel UARTCNT
        tstfsz  UARTCNT                     ;check if uart received anything
        call	RS232UartReceived
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

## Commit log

2013-09-26 hardware revision 0
    [univ_3-101-0-x-rev0.brd, univ_3-101-0-x-rev0.sch]
2014-08-10 firmware revision 0
    [univ_3-101-0-1-rev0-memory.xls]
2014-08-10 firmware UNIV 3.101.0.1 revision 0
    [univ_3-101-0-1-rev0-memory.xls]
2016-05-28 hardware UNIV 3.101.0.x revision 0
    [univ_3-101-0-x-rev0.brd, univ_3-101-0-x-rev0.sch]
2016-05-28 hardware UNIV 3.101.0.x revision 1
    [pcb_univ_3-101-0-x-rev1.brd, pcb_univ_3-101-0-x-rev1.sch]
2017-12-28 firmware UNIV 3.101.0.1 revision 1
    [univ_3-101-0-1-rev1-memory.xls]
2021-07-23 hardware UNIV 3.101.0.x revision 2
    [pcb_univ_3-101-0-x-rev2.brd, pcb_univ_3-101-0-x-rev2.sch]
2024-07-04 (hardware) rev3 with RS233 via FTDI USB and ADUM isolators
    [pcb_univ_3-101-0-x-rev2.brd, pcb_univ_3-101-0-x-rev2.sch]

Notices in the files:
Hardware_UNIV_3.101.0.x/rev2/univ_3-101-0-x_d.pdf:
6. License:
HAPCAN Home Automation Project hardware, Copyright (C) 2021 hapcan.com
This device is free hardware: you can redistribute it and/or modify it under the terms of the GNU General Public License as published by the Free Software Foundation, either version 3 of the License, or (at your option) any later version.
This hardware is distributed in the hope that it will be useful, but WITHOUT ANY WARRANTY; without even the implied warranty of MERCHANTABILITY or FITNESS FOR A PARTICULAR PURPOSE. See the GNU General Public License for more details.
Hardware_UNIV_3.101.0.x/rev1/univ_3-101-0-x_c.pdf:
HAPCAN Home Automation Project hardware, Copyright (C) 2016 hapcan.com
